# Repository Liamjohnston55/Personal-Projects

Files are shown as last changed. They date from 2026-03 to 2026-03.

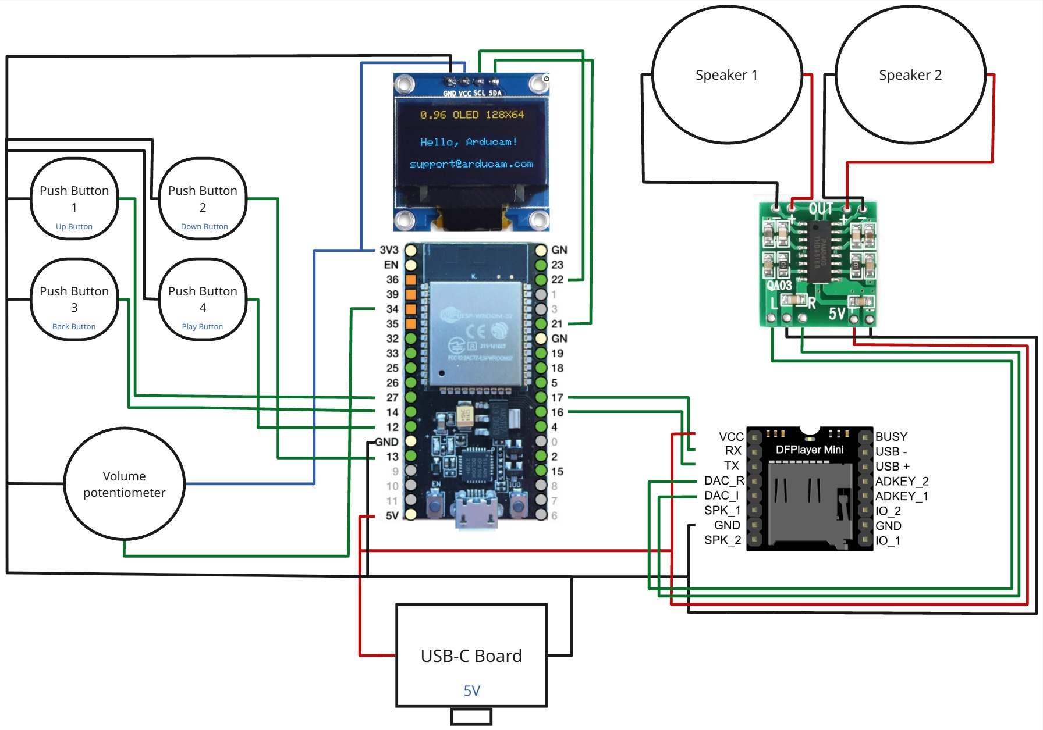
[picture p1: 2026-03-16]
mp3-jukebox/Docs/Electrical_Integration_Diagram.png

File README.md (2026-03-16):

# Personal Projects

This repository contains personal electrical and software engineering projects focused on embedded systems, PCB design, and hardware integration.

Most of these projects are built from the ground up, including:
- Firmware development (ESP32, Arduino framework)
- Custom PCB schematic and layout in KiCad
- Hardware debugging and system integration
- 3D printed mechanical design
- Power management and battery systems

The goal of these projects is practical system implementation — taking a concept from idea to working hardware.

---

## Projects

### ESP32 MP3 Jukebox
Custom embedded audio system built around an ESP32 with a fully designed PCB, firmware, and enclosure.

Includes:
- ESP32 firmware
- Custom KiCad schematic and PCB layout
- Gerber manufacturing files
- Mechanical STL files
- System documentation

Project folder: `MP3 Jute Box/`

---

More projects will be added as they are completed.

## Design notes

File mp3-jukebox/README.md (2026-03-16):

# ESP32 MP3 Jukebox

Custom embedded audio system designed using an ESP32 microcontroller.  
This project includes firmware development, custom PCB design in KiCad, and a 3D printed enclosure.

The system reads MP3 files from a microSD card and provides button-based navigation with OLED display feedback.

---

## System Overview

The jukebox consists of:

- ESP32-WROOM-32 (main controller)
- DFPlayer Mini (DFR0299) MP3 module
- PAM8403 3W Class-D audio amplifier
- 0.96" SSD1306 I2C OLED display
- Pushbutton user interface
- Analog volume control
- 18650 battery-powered system

The ESP32 handles user input, display rendering, power management, and DFPlayer communication over UART.

---

## Features

- Menu-based song selection
- OLED track display
- Loop playback
- Analog volume control
- Deep sleep power management
- Custom PCB layout
- Custom 3D printed enclosure

---

## Hardware

All hardware was designed and integrated manually.

PCB Design:
- Designed in KiCad
- Two-layer board
- Custom routing and layout
- Gerber files included for manufacturing

Location:
`Hardware/ESP32_MP3_Jukebox/`

---

## Firmware

- Arduino framework for ESP32
- UART2 communication with DFPlayer
- I2C OLED display control
- Button debouncing logic
- Deep sleep implementation

Location:
`Code/`

---

## Mechanical Design

The enclosure and mounting components were designed for 3D printing.

Location:
`Mechanical/`

---

## Manufacturing

Gerber files are included for PCB fabrication.

`Hardware/ESP32_MP3_Jukebox/ESP32_MP3_Jukebox_Gerbers/`

---

## External Libraries and References

The following third-party resources were used for schematic symbols and PCB footprints:

- **DFPlayer Mini (DFR0299)** – SnapEDA  
  https://www.snapeda.com/parts/DFR0299/DFRobot/view-part/

- **ESP32 KiCad Libraries** – Espressif  
  https://github.com/espressif/kicad-libraries

- **SSD1306 128x64 OLED KiCad Library** – pforrmi  
  https://github.com/pforrmi/KiCad-SSD1306-128x64

- **PAM8403 Module KiCad Library** – johnnycubides  
  https://github.com/johnnycubides/pam8403-module-kicad-lib

All third-party libraries remain property of their respective authors and are used in accordance with their licenses.

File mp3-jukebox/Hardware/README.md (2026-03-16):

# Hardware Design – ESP32 MP3 Jukebox

This folder contains the complete KiCad project files for the custom
ESP32-based MP3 Jukebox PCB.

## Overview

The PCB integrates:

- ESP32-WROOM-32 Dev Board
- DFPlayer Mini (DFR0299)
- SSD1306 128x64 I2C OLED
- PAM8403 Audio Amplifier
- Pushbutton GPIO inputs
- Analog volume control (ADC)
- 5V USB-C power input

The design is a 2-layer PCB with dedicated power and signal routing.

---

## Files Included

- `.kicad_pro` – KiCad project file  
- `.kicad_sch` – Complete schematic  
- `.kicad_pcb` – PCB layout  
- `Gerbers/` – Manufacturing-ready Gerber files  
- `Libraries/` – External symbol and footprint files used  

---

## Manufacturing

The Gerber files were generated using KiCad 9.0.

To fabricate:

1. Upload the `Gerbers/` folder as a zip file to:
   - JLCPCB
   - PCBWay
   - Any standard PCB manufacturer

2. Standard settings:
   - 2-layer board
   - 1.6mm thickness
   - HASL finish
   - 1oz copper

---

## Design Notes

- Separate analog and digital routing where possible.
- Audio lines kept short to minimize noise.
- Power rails routed with wider traces.
- Mounting holes included for enclosure integration.

---

## External Libraries Used

- DFPlayer Mini (DFR0299) – SnapEDA  
- ESP32 DevKit – Espressif KiCad Libraries  
- SSD1306 OLED – KiCad-SSD1306-128x64  
- PAM8403 Amplifier – pam8403-module-kicad-lib  

See main README for full repository links.

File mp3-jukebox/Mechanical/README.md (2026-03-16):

## Mechanical Design

The enclosure consists of a two-piece housing:

- `enclosure_bottom.stl`
- `enclosure_top.stl`

Custom-designed mounting components include:

- `dfplayer_mount_adapter.stl` – Secures the DFPlayer Mini module to the enclosure.
- `usb_c_mount.stl` – Mounting interface for the USB-C charging board.
- Internal support features integrated into the enclosure base.

Third-party mechanical components were used for:

- Screen holder – Thingiverse  
  https://www.thingiverse.com/thing:2176764

- 6mm tactile button enclosure – Cults3D (CC BY-SA)  
  https://cults3d.com/en/3d-model/tool/enclosure-for-6mm-tactile-button-switch

All third-party models remain property of their respective authors and are used in accordance with their licenses.

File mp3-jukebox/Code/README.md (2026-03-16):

# Firmware Information

Platform: ESP32-WROOM-32  
IDE: Arduino IDE 2.3.8  

## Pin Assignments

| Function | GPIO |
|---|---|
| BTN_UP | 13 |
| BTN_DOWN | 27 |
| BTN_PLAY | 14 |
| BTN_BACK | 12 |
| Volume (ADC) | 34 |
| DFPlayer RX  | 16 |
| DFPlayer TX  | 17 |
| OLED SDA | 21 |
| OLED SCL | 22 |

## Required Libraries

- Adafruit SSD1306
- Adafruit GFX
- DFRobotDFPlayerMini

## Upload Instructions

1. Install ESP32 board support.
2. Install required libraries.
3. Select "ESP32 Dev Module".
4. Upload `mp3_jukebox.ino`.

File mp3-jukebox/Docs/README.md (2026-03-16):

# Documentation

This folder contains wiring diagrams and system reference documentation.

- Electrical_Integration_Diagram.png
- System_Architecture_Diagram.png
- Pin_Assignment_Table.md

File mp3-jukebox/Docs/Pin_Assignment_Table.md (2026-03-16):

# Pin Assignment Table

| Function | ESP32 Pin | Connected To | Interface | Notes |
|---|---|---|---|---|
| DFPlayer TX | GPIO17 | DFPlayer RX | UART | Serial communication |
| DFPlayer RX | GPIO16 | DFPlayer TX | UART | Serial communication |
| OLED SDA | GPIO21 | OLED SDA | I2C | Display data |
| OLED SCL | GPIO22 | OLED SCL | I2C | Display clock |
| Button 1 (Up) | GPIO27 | Push Button | GPIO | Digital input |
| Button 2 (Down) | GPIO13 | Push Button | GPIO | Digital input |
| Button 3 (Back) | GPIO14 | Push Button | GPIO | Digital input |
| Button 4 (Play) | GPIO12 | Push Button | GPIO | Digital input |
| Volume Potentiometer  | GPIO34 | Potentiometer | ADC | Analog input |
| 5V Input | 5V Pin | USB-C Board Output | Power | Main supply rail |
| Common Ground | GND | All modules | Power | Shared ground |

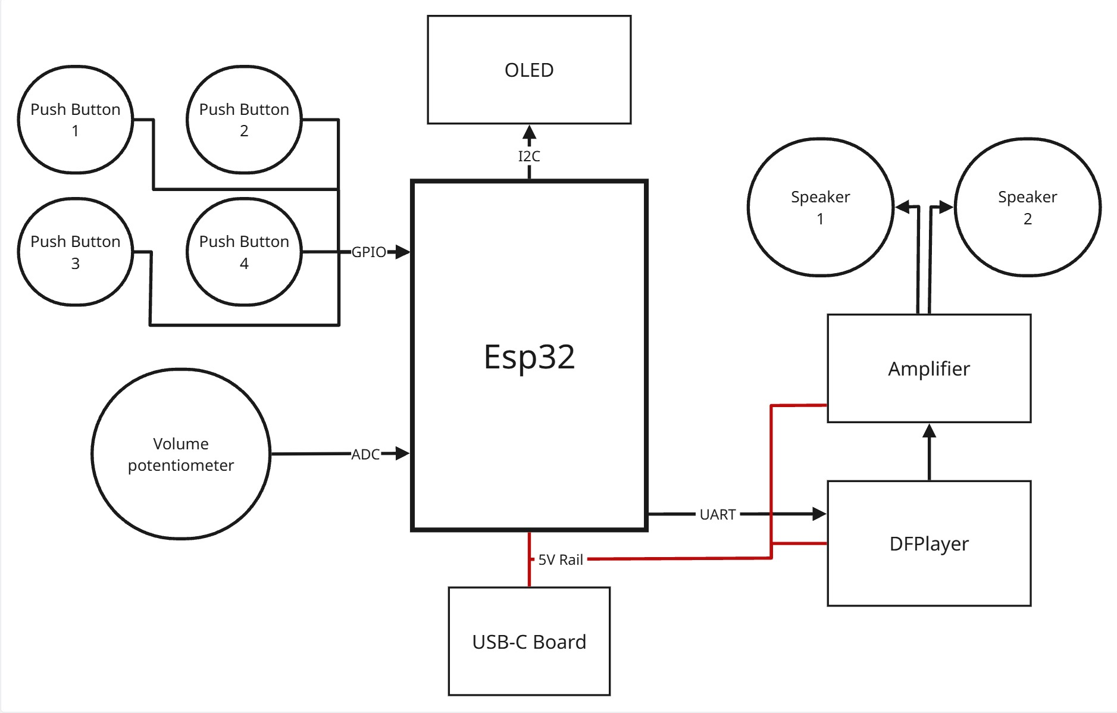
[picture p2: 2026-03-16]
mp3-jukebox/Docs/System_Architecture_Diagram.png

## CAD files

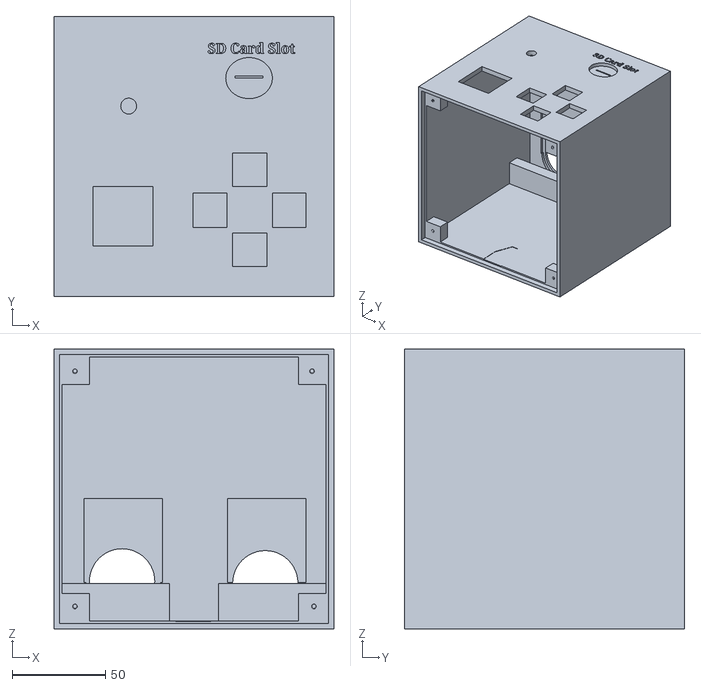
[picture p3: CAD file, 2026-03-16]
mp3-jukebox/Mechanical/Custom_Designed/main_housing.stl
150.0 x 150.0 x 150.0

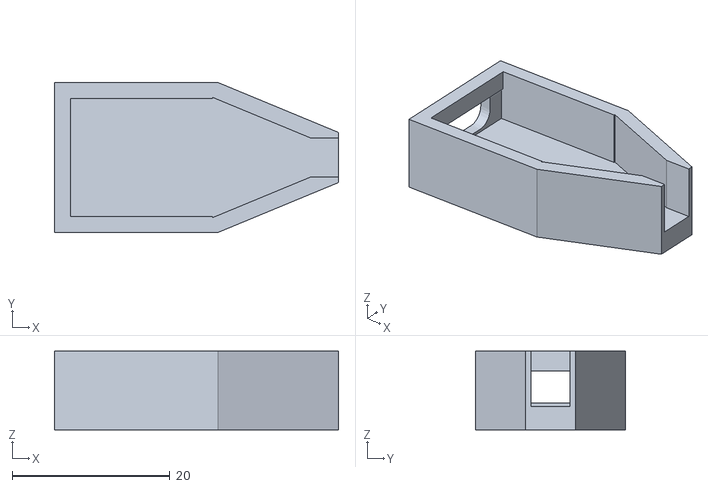
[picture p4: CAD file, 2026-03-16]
mp3-jukebox/Mechanical/Custom_Designed/usb_c_board_mount.stl
36.0 x 19.0 x 10.0

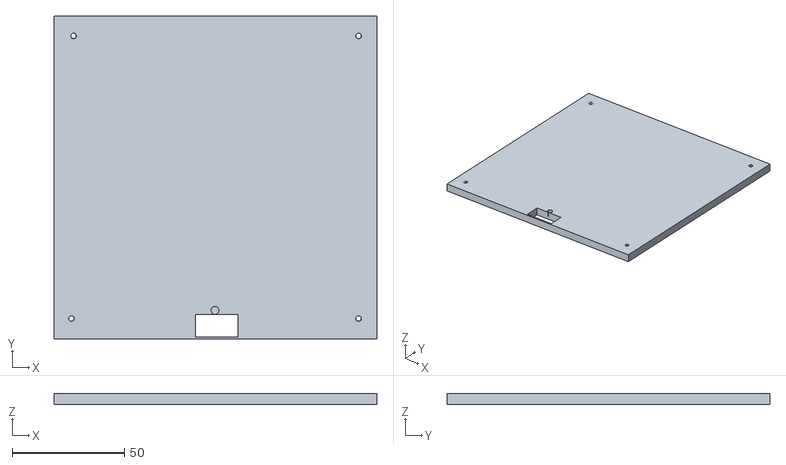
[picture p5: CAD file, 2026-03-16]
mp3-jukebox/Mechanical/Custom_Designed/housing_cover.stl
144.0 x 144.0 x 5.00

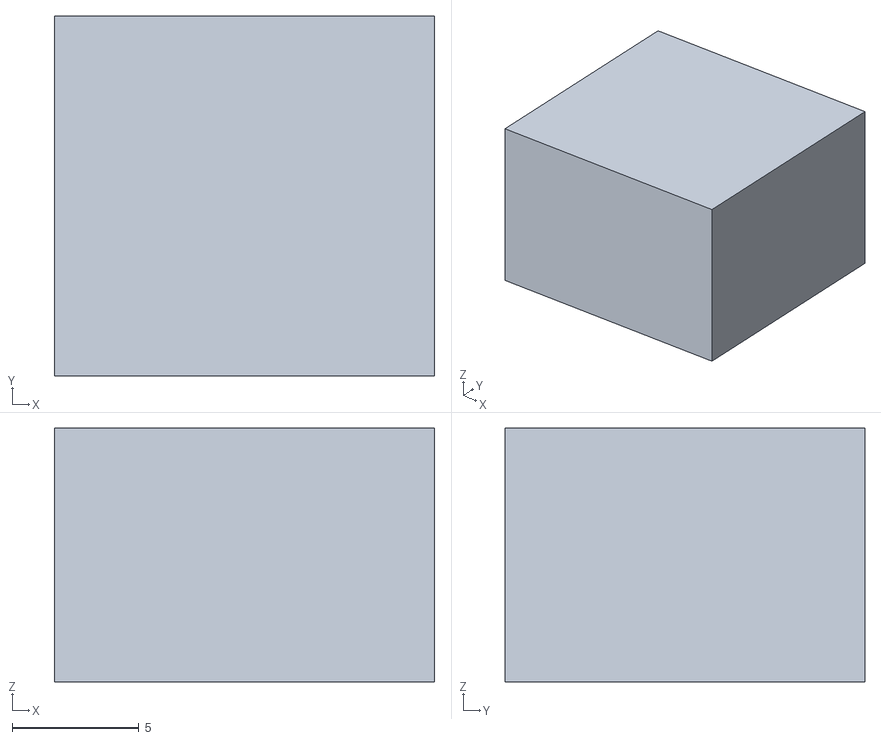
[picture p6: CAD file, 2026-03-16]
mp3-jukebox/Mechanical/Custom_Designed/dfplayer_mount_adapter.stl
15.0 x 14.2 x 10.00

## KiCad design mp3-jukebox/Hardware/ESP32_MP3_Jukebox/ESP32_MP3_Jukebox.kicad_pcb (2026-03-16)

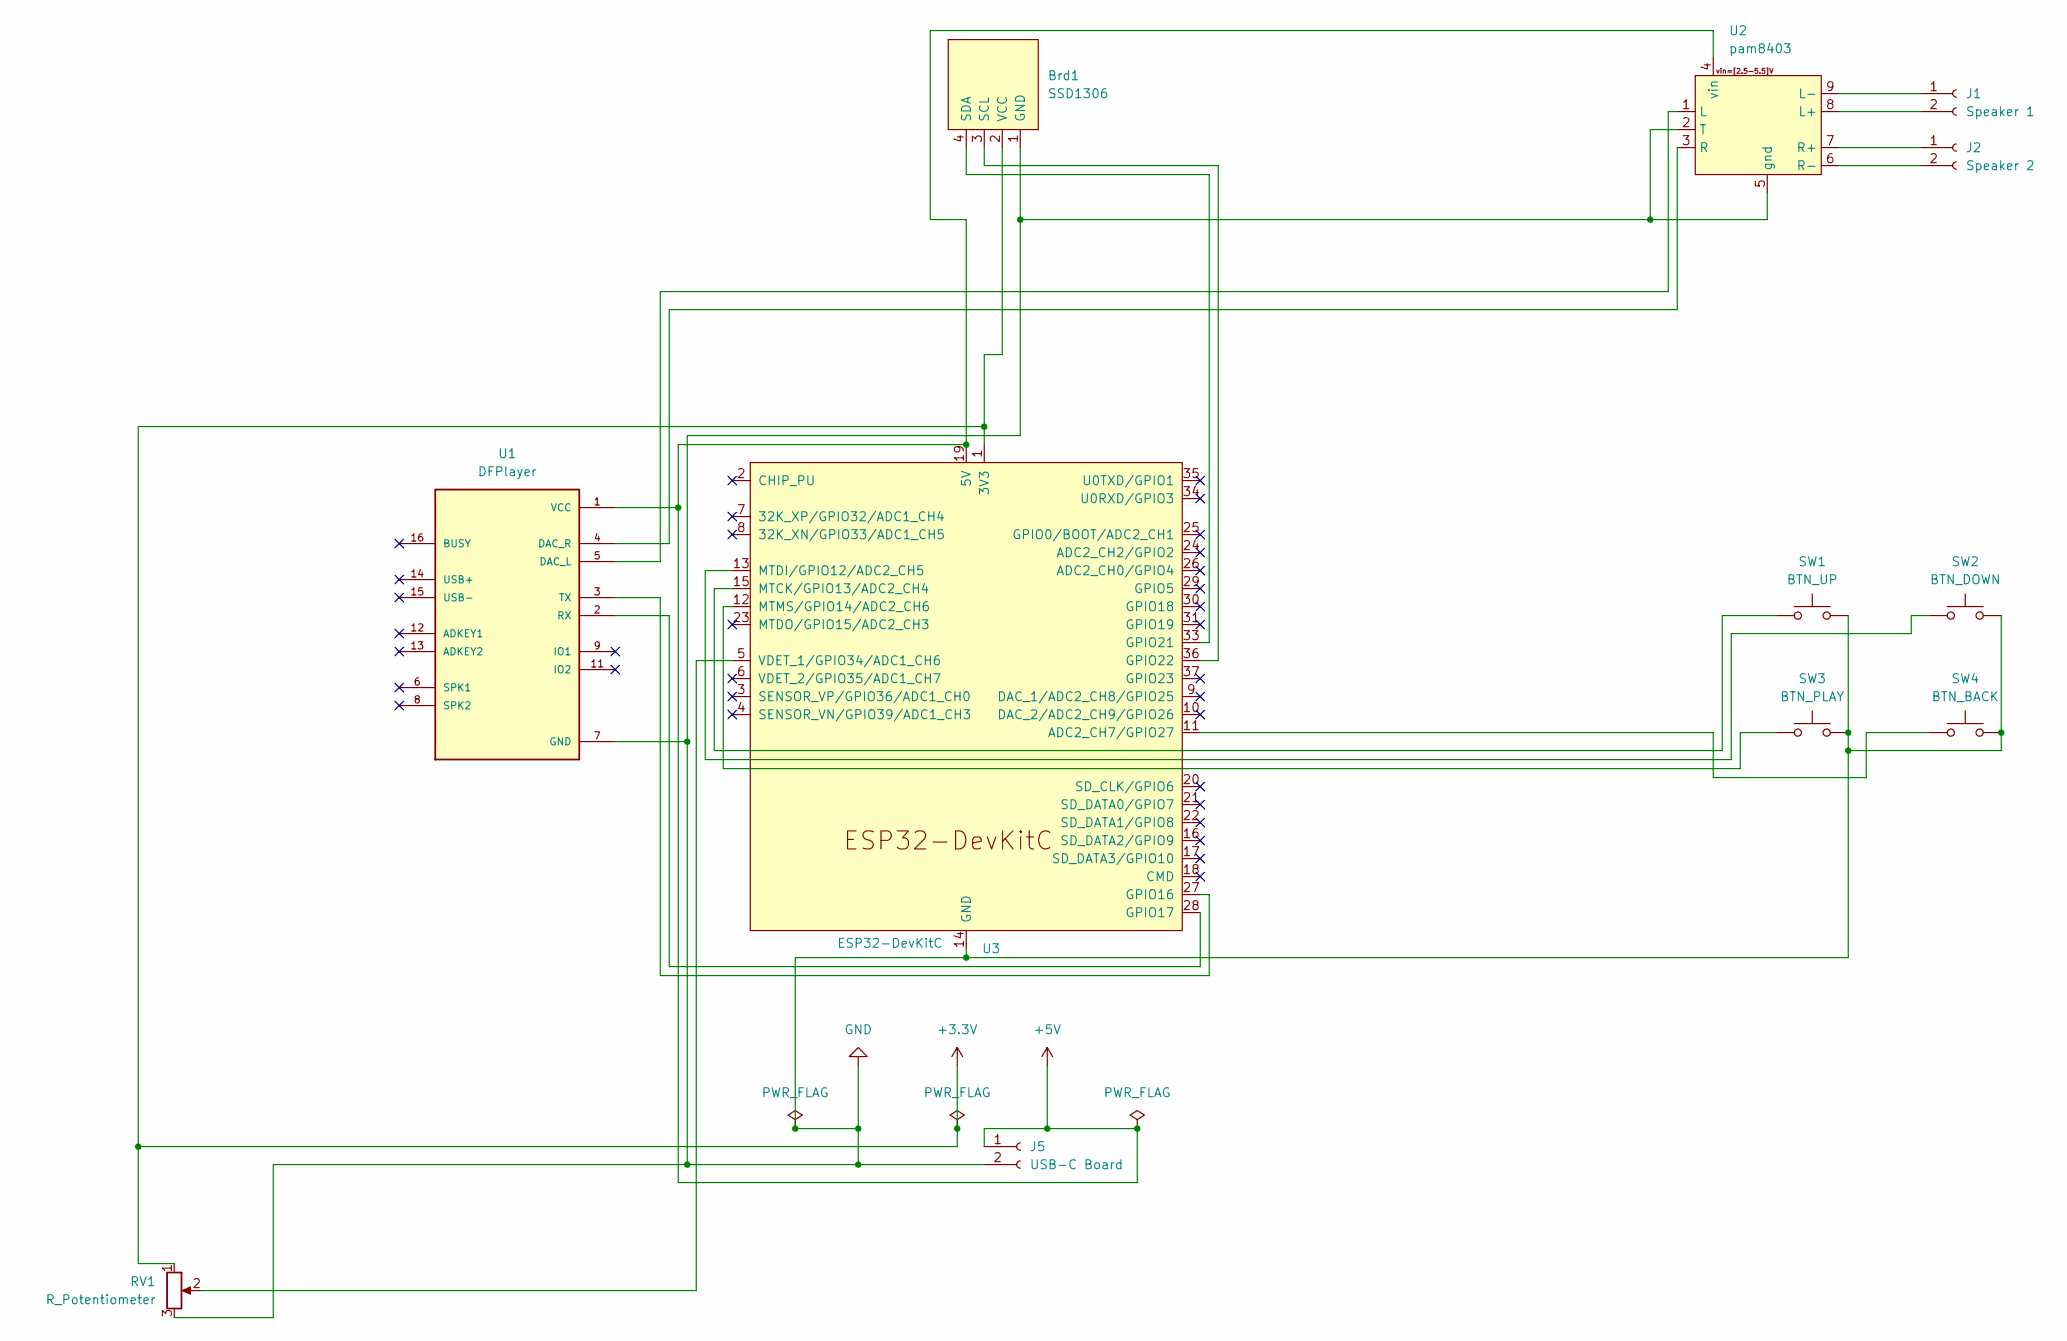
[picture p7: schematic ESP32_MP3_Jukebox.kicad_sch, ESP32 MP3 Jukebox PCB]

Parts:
Brd1: SSD1306; PinHeader_1x04_P2.54mm_Vertical
J1: Speaker 1; PinHeader_1x02_P2.54mm_Vertical
J2: Speaker 2; PinHeader_1x02_P2.54mm_Vertical
J5: USB-C Board; PinHeader_1x02_P2.54mm_Vertical
RV1: R_Potentiometer; PinHeader_1x03_P2.54mm_Vertical
SW1: BTN_UP; PinHeader_1x02_P2.54mm_Vertical
SW2: BTN_DOWN; PinHeader_1x02_P2.54mm_Vertical
SW3: BTN_PLAY; PinHeader_1x02_P2.54mm_Vertical
SW4: BTN_BACK; PinHeader_1x02_P2.54mm_Vertical
U1: DFPlayer; MODULE_DFR0299
U2: pam8403
U3: ESP32-DevKitC

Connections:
+3.3V: Brd1.2 (VCC), RV1.1, U3.1 (3V3)
+5V: J5.1, U1.1 (VCC), U2.4 (vin), U3.19 (5V)
GND: Brd1.1 (GND), J5.2, RV1.3, SW1.2, SW2.2, SW3.2, SW4.2, U1.7 (GND), U1.10 (GND), U2.2 (T), U2.5 (gnd), U3.14 (GND), U3.32 (GND), U3.38 (GND)
unnamed: Brd1.3 (SCL), U3.36 (GPIO22)
unnamed: Brd1.4 (SDA), U3.33 (GPIO21)
unnamed: J1.1, U2.9 (L-)
unnamed: J1.2, U2.8 (L+)
unnamed: J2.1, U2.7 (R+)
unnamed: J2.2, U2.6 (R-)
unnamed: U1.5 (DAC_L), U2.1 (L)
unnamed: U1.4 (DAC_R), U2.3 (R)
unnamed: U1.2 (RX), U3.28 (GPIO17)
unnamed: U1.3 (TX), U3.27 (GPIO16)
unnamed: SW4.1, U3.11 (ADC2_CH7/GPIO27)
unnamed: SW1.1, U3.15 (MTCK/GPIO13/ADC2_CH4)
unnamed: SW2.1, U3.13 (MTDI/GPIO12/ADC2_CH5)
unnamed: SW3.1, U3.12 (MTMS/GPIO14/ADC2_CH6)
unnamed: RV1.2, U3.5 (VDET_1/GPIO34/ADC1_CH6)

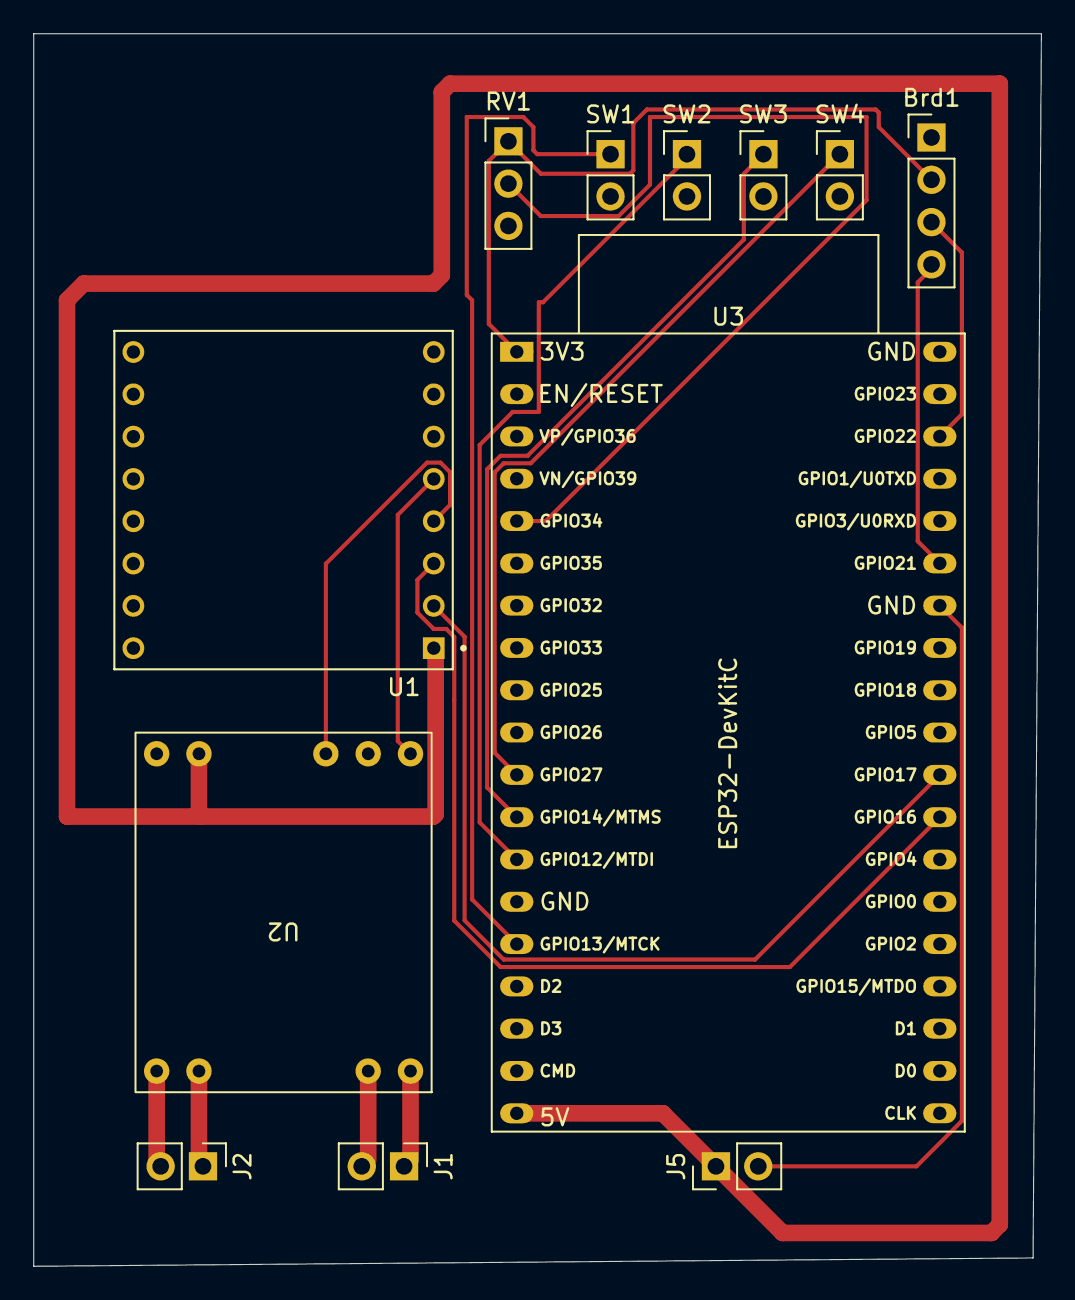
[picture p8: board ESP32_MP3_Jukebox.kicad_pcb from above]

Board: 2 copper layers, 60.5 x 74.0 mm, 12 parts (0 on the bottom side), 18 nets.

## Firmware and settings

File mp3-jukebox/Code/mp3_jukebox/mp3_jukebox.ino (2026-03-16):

/*
===============================================================================
Project: ESP32 MP3 Jukebox
Author: Liam Johnston
Target: ESP32-WROOM-32
Framework: Arduino ESP32 Core

Overview:
Button-driven MP3 jukebox using an ESP32 + DFPlayer Mini with OLED feedback
and analog volume control. A static track list is defined in firmware.
Selected tracks loop until stopped.

Hardware Interfaces:
- UART2  : DFPlayer Mini (9600 baud)
- I2C    : SSD1306 OLED (0x3C)
- GPIO   : Active-low pushbuttons (internal pull-ups)
- ADC    : Potentiometer volume input (0..4095 → 0..30)
- Audio  : DFPlayer → PAM8403 amplifier → speakers

Notes:
- Song titles are defined in firmware.
- DFPlayer does not support filename enumeration over UART.
===============================================================================
*/

#include <Arduino.h>
#include <Wire.h>
#include <Adafruit_GFX.h>
#include <Adafruit_SSD1306.h>
#include <HardwareSerial.h>
#include <DFRobotDFPlayerMini.h>
#include "esp_sleep.h"

// -------- Logging --------
#ifndef LOG_ENABLE
#define LOG_ENABLE 1
#endif

#if LOG_ENABLE
  #define LOG_INFO(msg)   do { Serial.print("[INFO] ");  Serial.println(msg); } while (0)
  #define LOG_WARN(msg)   do { Serial.print("[WARN] ");  Serial.println(msg); } while (0)
  #define LOG_ERROR(msg)  do { Serial.print("[ERROR] "); Serial.println(msg); } while (0)
#else
  #define LOG_INFO(msg)   do {} while (0)
  #define LOG_WARN(msg)   do {} while (0)
  #define LOG_ERROR(msg)  do {} while (0)
#endif

// -------- OLED --------
static constexpr int SCREEN_WIDTH  = 128;
static constexpr int SCREEN_HEIGHT = 64;
static constexpr uint8_t OLED_ADDR = 0x3C;

Adafruit_SSD1306 display(SCREEN_WIDTH, SCREEN_HEIGHT, &Wire, -1);

// -------- Pin Definitions --------
static constexpr int BTN_DOWN = 27;
static constexpr int BTN_PLAY = 14;
static constexpr int BTN_BACK = 12;
static constexpr int BTN_UP   = 13;

static constexpr int VOL_PIN  = 34;

static constexpr int DF_RX_PIN = 16;  // ESP32 RX2  <- DFPlayer TX
static constexpr int DF_TX_PIN = 17;  // ESP32 TX2  -> DFPlayer RX

// -------- DFPlayer --------
HardwareSerial DFSerial(2);
DFRobotDFPlayerMini mp3;

// -------- Song List --------
struct SongNameEntry {
  uint16_t trackNum;
  const char* name;
};

static SongNameEntry SONG_NAMES[] = {
  {1, "Miku"},
  {2, "Minecraft C418"},
  {3, "Medium Waterfall"},
  {4, "Pokemon SS music"},
};

static constexpr int SONG_NAME_COUNT =
    sizeof(SONG_NAMES) / sizeof(SONG_NAMES[0]);

// -------- Timing --------
static constexpr uint32_t MENU_SLEEP_TIMEOUT_MS   = 60000;
static constexpr uint32_t BOOT_SCREEN_MS          = 5000;
static constexpr uint32_t MENU_DEBOUNCE_MS        = 120;
static constexpr uint32_t PLAY_START_DELAY_MS     = 200;
static constexpr uint32_t PLAYBACK_UI_REFRESH_MS  = 1000;

// -------- State --------
enum UiState : uint8_t {
  STATE_MENU,
  STATE_PLAYING
};

static UiState uiState = STATE_MENU;

static int      menuIndex      = 0;
static uint16_t currentTrack   = 0;
static bool     isPlaying      = false;

static uint32_t songStartMs        = 0;
static uint32_t lastInteractionMs  = 0;
static uint32_t lastUiActionMs     = 0;
static uint32_t lastPlaybackDrawMs = 0;

static int currentVolume = 20;

// -------- Button State Tracking --------
static bool lastDown  = false;
static bool lastUp    = false;
static bool lastPlay  = false;
static bool lastBack  = false;

static bool buttonFell(int pin, bool &lastState) {
  bool now = (digitalRead(pin) == LOW);
  bool pressedEdge = (now && !lastState);
  lastState = now;
  return pressedEdge;
}

// -------- Helpers --------
static const char* getSongNameByIndex(int idx) {
  if (idx < 0 || idx >= SONG_NAME_COUNT) return "?";
  return SONG_NAMES[idx].name;
}

static uint16_t getTrackNumByIndex(int idx) {
  if (idx < 0 || idx >= SONG_NAME_COUNT) return 1;
  return SONG_NAMES[idx].trackNum;
}

static bool uiRateLimitOk(uint32_t nowMs) {
  if (nowMs - lastUiActionMs < MENU_DEBOUNCE_MS)
    return false;

  lastUiActionMs = nowMs;
  return true;
}

// -------- Boot Screen --------
static void drawBootScreen() {
  display.clearDisplay();
  display.setTextSize(1);
  display.setTextColor(SSD1306_WHITE);

  display.setCursor(0, 4);
  display.println("Minecraft Jukebox");

  display.display();
}

// -------- Menu UI --------
static void drawMenu() {
  display.clearDisplay();
  display.setTextSize(1);
  display.setTextColor(SSD1306_WHITE);

  display.setCursor(0, 0);
  display.println("Select Song");

  if (SONG_NAME_COUNT == 0) {
    display.setCursor(0, 20);
    display.println("No songs listed");
    display.display();
    return;
  }

  int baseY = 20;
  int lineH = 14;

  int prevIdx = (menuIndex - 1 + SONG_NAME_COUNT) % SONG_NAME_COUNT;
  int nextIdx = (menuIndex + 1) % SONG_NAME_COUNT;

  display.setCursor(0, baseY);
  display.print("  ");
  display.println(getSongNameByIndex(prevIdx));

  display.setCursor(0, baseY + lineH);
  display.print("> ");
  display.println(getSongNameByIndex(menuIndex));

  display.setCursor(0, baseY + 2 * lineH);
  display.print("  ");
  display.println(getSongNameByIndex(nextIdx));

  display.display();
}

// -------- Playback UI --------
static void drawPlayback() {
  display.clearDisplay();
  display.setTextSize(1);
  display.setTextColor(SSD1306_WHITE);

  display.setCursor(0, 18);
  display.println("Playing:");
  display.println(getSongNameByIndex(menuIndex));

  uint32_t elapsed = (millis() - songStartMs) / 1000;
  uint32_t min = elapsed / 60;
  uint32_t sec = elapsed % 60;

  display.print("Time: ");
  display.print(min);
  display.print(":");
  if (sec < 10) display.print("0");
  display.println(sec);

  int volPct = map(currentVolume, 0, 30, 0, 100);
  display.print("Vol: ");
  display.print(volPct);
  display.println("%");

  display.display();
}

// -------- Volume --------
static void updateVolume() {
  int raw = analogRead(VOL_PIN);
  int vol = map(raw, 0, 4095, 0, 30);

  if (abs(vol - currentVolume) >= 1) {
    currentVolume = vol;
    mp3.volume(currentVolume);
  }
}

// -------- Playback Control --------
static void startTrackByIndex(int idx) {
  uint16_t trackNum = getTrackNumByIndex(idx);

  currentTrack = trackNum;
  isPlaying = true;
  songStartMs = millis();

  LOG_INFO(String("Starting track ") + trackNum);

  mp3.play(trackNum);
  delay(PLAY_START_DELAY_MS);
  mp3.loop(trackNum);

  drawPlayback();
}

static void stopTrack() {
  LOG_INFO("Stopping playback");
  mp3.stop();
  isPlaying = false;
  currentTrack = 0;
  uiState = STATE_MENU;
  drawMenu();
}

// -------- Sleep --------
static void goToSleep() {
  LOG_INFO("Entering deep sleep (menu idle timeout)");

  esp_sleep_enable_ext1_wakeup(
    (1ULL << BTN_UP) |
    (1ULL << BTN_DOWN) |
    (1ULL << BTN_PLAY) |
    (1ULL << BTN_BACK),
    ESP_EXT1_WAKEUP_ANY_LOW
  );

  delay(100);
  esp_deep_sleep_start();
}

// -------- Setup --------
void setup() {
  Serial.begin(115200);
  delay(200);

  pinMode(BTN_DOWN, INPUT_PULLUP);
  pinMode(BTN_UP,   INPUT_PULLUP);
  pinMode(BTN_PLAY, INPUT_PULLUP);
  pinMode(BTN_BACK, INPUT_PULLUP);
  pinMode(VOL_PIN,  INPUT);

  if (!display.begin(SSD1306_SWITCHCAPVCC, OLED_ADDR)) {
    LOG_ERROR("OLED init failed");
    while (true) delay(100);
  }

  drawBootScreen();
  delay(BOOT_SCREEN_MS);

  DFSerial.begin(9600, SERIAL_8N1, DF_RX_PIN, DF_TX_PIN);

  if (!mp3.begin(DFSerial, true, true)) {
    LOG_ERROR("DFPlayer not detected");
    while (true) delay(500);
  }

  mp3.outputDevice(DFPLAYER_DEVICE_SD);
  mp3.EQ(DFPLAYER_EQ_NORMAL);

  mp3.volume(currentVolume);

  drawMenu();

  lastInteractionMs  = millis();
  lastUiActionMs     = millis();
  lastPlaybackDrawMs = millis();
}

// -------- Main Loop --------
void loop() {
  uint32_t now = millis();

  updateVolume();

  bool downPressed = buttonFell(BTN_DOWN, lastDown);
  bool upPressed   = buttonFell(BTN_UP,   lastUp);
  bool playPressed = buttonFell(BTN_PLAY, lastPlay);
  bool backPressed = buttonFell(BTN_BACK, lastBack);

  if (downPressed || upPressed || playPressed || backPressed)
    lastInteractionMs = now;

  if (uiState == STATE_MENU &&
      (now - lastInteractionMs > MENU_SLEEP_TIMEOUT_MS)) {
    goToSleep();
  }

  if (uiState == STATE_MENU) {
    if (downPressed && uiRateLimitOk(now)) {
      menuIndex = (menuIndex + 1) % SONG_NAME_COUNT;
      drawMenu();
    }

    if (upPressed && uiRateLimitOk(now)) {
      menuIndex = (menuIndex - 1 + SONG_NAME_COUNT) % SONG_NAME_COUNT;
      drawMenu();
    }

    if (playPressed) {
      uiState = STATE_PLAYING;
      startTrackByIndex(menuIndex);
      lastPlaybackDrawMs = now;
    }
  }
  else {
    if (backPressed) {
      stopTrack();
    }
    else if (now - lastPlaybackDrawMs >= PLAYBACK_UI_REFRESH_MS) {
      drawPlayback();
      lastPlaybackDrawMs = now;
    }
  }

  // Small loop pacing delay to reduce CPU load
  delay(10);
}

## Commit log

2026-03-16 Initial commit: add ESP32 MP3 Jukebox project
    Add complete ESP32-based MP3 Jukebox project including firmware,
    hardware design files, and documentation.
    This commit includes:
    - ESP32 firmware implementing menu navigation, OLED display output,
    DFPlayer Mini communication, and playback control
    - KiCad schematic and PCB layout for the custom ESP32 MP3 Jukebox board
    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
    [ESP32_MP3_Jukebox-B_Cu.gbr, ESP32_MP3_Jukebox-B_Mask.gbr, ESP32_MP3_Jukebox-B_Silkscreen.gbr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]
2026-03-17 Renamed project files for consistency and improved organization
    [ESP32_MP3_Jukebox-B_Cu.gbr, ESP32_MP3_Jukebox-B_Mask.gbr, ESP32_MP3_Jukebox-B_Silkscreen.gbr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]
